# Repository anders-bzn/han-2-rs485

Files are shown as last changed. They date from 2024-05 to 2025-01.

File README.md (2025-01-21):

# han-2-rs485
A small board that converts signal level from the HAN-port on swedish electricity power meter to RS-485. There is no connection for ground so a galvanically separated receiver is recommended. The board fits into a small ELKO standard connection box.

Created with KiCad 7.0 and [kicad-jlcpcb-tools](https://github.com/Bouni/kicad-jlcpcb-tools) plugin for creating fabrication files.

This is used together with a Raspberry Pi with a RS-485 HAT

## Software
Small python program for publishing MQTT data is located in the sw folder. It has one script that sets up the RPi and installs a service. The p1_sensors.yaml is a template for mapping sensors into Home Assistant. The content should be pasted into configuration.yaml in Home Assistant.

Change the han-mqtt-config.yaml with mqtt settings and report interval. Then install configuration and service by running:

    sudo ./han-mqtt.sh

## Acknowledgement
Acknowledgement to this github project: https://github.com/UdoK/esp8266_p1meter_sv from which I copied the mqtt topics.

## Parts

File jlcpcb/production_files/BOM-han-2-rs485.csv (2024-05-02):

Comment | Designator | Footprint | LCSC
USBLC6-2P6 | U2 | SOT-666
4k7 | R4 | R_0805_2012Metric
4k7 | R3 | R_0805_2012Metric
RJ12 | J1 | RJ12_Amphenol_54601
RJ45 | J2 | RJ45_Amphenol_54602-x08_Horizontal
MAX485E | U1 | SOIC-8_3.9x4.9mm_P1.27mm
10k | R2 | R_0805_2012Metric
100n | C1 | C_0805_2012Metric_Pad1.18x1.45mm_HandSolder
120R | R1 | R_0805_2012Metric

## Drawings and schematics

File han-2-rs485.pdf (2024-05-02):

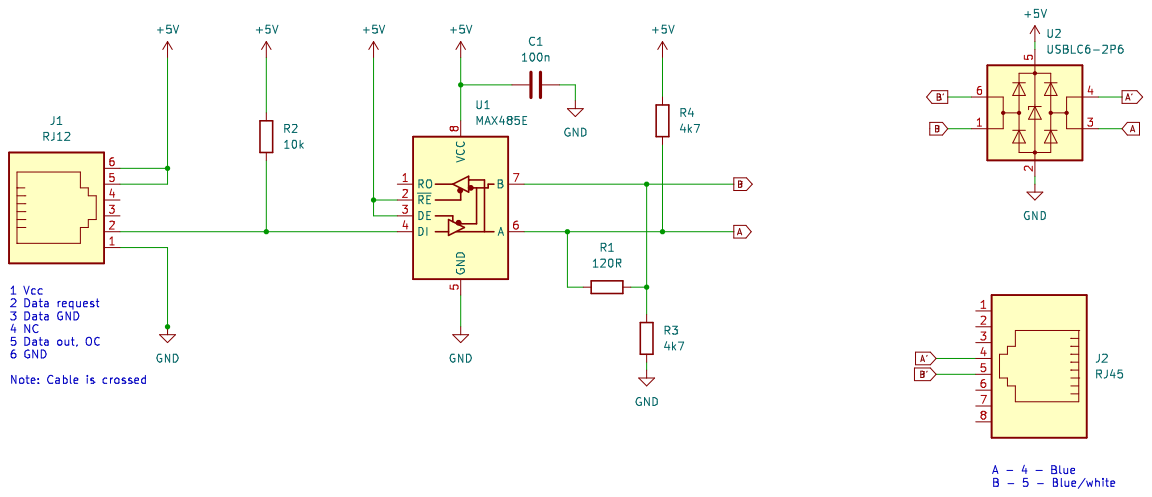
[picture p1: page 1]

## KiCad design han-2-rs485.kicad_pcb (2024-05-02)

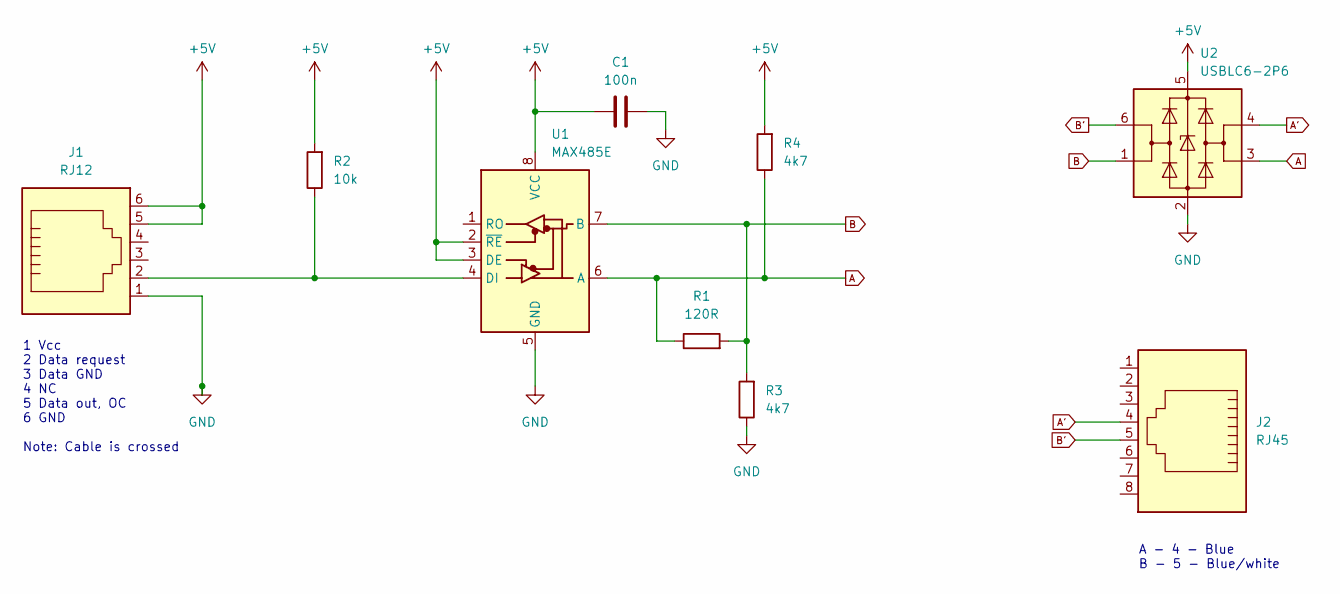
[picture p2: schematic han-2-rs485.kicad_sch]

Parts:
C1: 100n; C_0805_2012Metric_Pad1.18x1.45mm_HandSolder
J1: RJ12; RJ12_Amphenol_54601
J2: RJ45; RJ45_Amphenol_54602-x08_Horizontal
R1: 120R; R_0805_2012Metric
R2: 10k; R_0805_2012Metric
R3, R4: 4k7; R_0805_2012Metric
U1: MAX485E; SOIC-8_3.9x4.9mm_P1.27mm
U2: USBLC6-2P6; SOT-666

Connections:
+5V: C1.1, J1.5, J1.6, R2.2, R4.2, U1.2 (~RE), U1.3 (DE), U1.8 (VCC), U2.5 (VBUS)
A: R1.1, R4.1, U1.6 (A), U2.3 (I/O2)
A': J2.4, U2.4 (I/O2)
B: R1.2, R3.2, U1.7 (B), U2.1 (I/O1)
B': J2.5, U2.6 (I/O1)
GND: C1.2, J1.1, R3.1, U1.5 (GND), U2.2 (GND)
unnamed: J1.2, R2.1, U1.4 (DI)

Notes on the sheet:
1 Vcc 2 Data request 3 Data GND 4 NC 5 Data out, OC 6 GND Note: Cable is crossed
A - 4 - Blue B - 5 - Blue/white

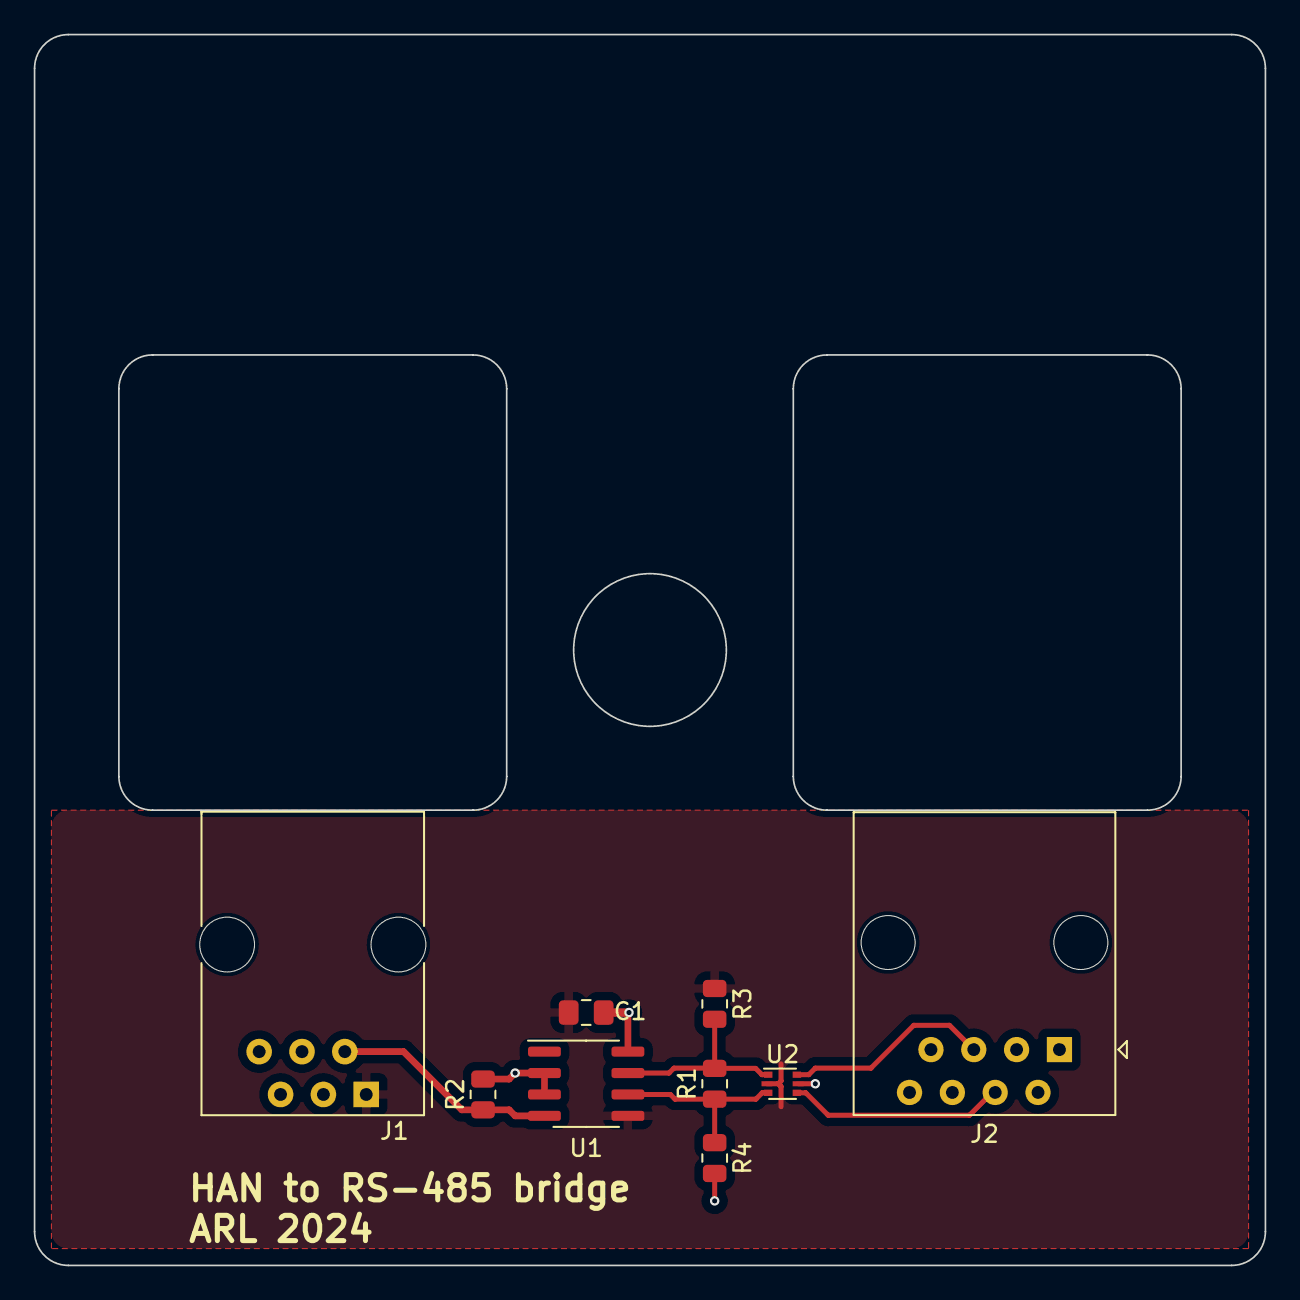
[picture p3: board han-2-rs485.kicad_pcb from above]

Board: 2 copper layers, 73.0 x 73.0 mm, 9 parts (0 on the bottom side), 7 nets.

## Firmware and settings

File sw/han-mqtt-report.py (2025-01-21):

#!/bin/python3

import os
import paho.mqtt.client as mqtt
import paho.mqtt.publish as publish
import re
import serial
import yaml

# Map telegram to mqtt topic
topics = {
    "0-0:1.0.0": "timestamp",
    "1-0:1.8.0": "consumption",
    "1-0:2.8.0": "return_delivery",
    "1-0:3.8.0": "consumption_reactive",
    "1-0:4.8.0": "return_delivery_reactive",
    "1-0:1.7.0": "actual_consumption",
    "1-0:2.7.0": "actual_return_delivery",
    "1-0:3.7.0": "actual_consumption_reactive",
    "1-0:4.7.0": "actual_return_delivery_reactive",
    "1-0:21.7.0": "l1_instant_power_usage",
    "1-0:22.7.0": "l1_instant_power_delivery",
    "1-0:23.7.0": "l1_reactive_power_usage",
    "1-0:24.7.0": "l1_reactive_power_delivery",
    "1-0:41.7.0": "l2_instant_power_usage",
    "1-0:42.7.0": "l2_instant_power_delivery",
    "1-0:43.7.0": "l2_reactive_power_usage",
    "1-0:44.7.0": "l2_reactive_power_delivery",
    "1-0:61.7.0": "l3_instant_power_usage",
    "1-0:62.7.0": "l3_instant_power_delivery",
    "1-0:63.7.0": "l3_reactive_power_usage",
    "1-0:64.7.0": "l3_reactive_power_delivery",
    "1-0:32.7.0": "l1_voltage",
    "1-0:52.7.0": "l2_voltage",
    "1-0:72.7.0": "l3_voltage",
    "1-0:31.7.0": "l1_current",
    "1-0:51.7.0": "l2_current",
    "1-0:71.7.0": "l3_current",
}

root_topic = "sensors/power/p1meter"

def loadConfig(config_file):
    with open(config_file, 'r') as ymlfile:
        try:
            config = yaml.safe_load(ymlfile)
        except yaml.YAMLError as exc:
            print(exc)
    return config

def main(config):
    config_yaml = loadConfig(config)

    # Initialize serial port
    try:
        ser = serial.Serial('/dev/ttyAMA0', 115200, timeout=12)
    except:
        print('FAIL: Could not open serial port')
        exit(1)

    # Initialize the mqtt connection
    client = mqtt.Client()

    if config_yaml['mqtt']['username'] != None and config_yaml['mqtt']['password'] != None:
        client.username_pw_set(config_yaml['mqtt']['username'], config_yaml['mqtt']['password'])

    client.connect(config_yaml['mqtt']['broker'])
    client.loop_start()

    interval = int(config_yaml['mqtt']['report_interval'])

    while True:
        # Just use one telegram of out ten
        for i in range(interval):
            mvpos=0
            line = ser.readline()
            while line[0] != ord('/'):
                line = ser.readline()

        while line[0] != ord('!'):
            line = ser.readline()
            data = (re.split('\*|W|\(', str(line)[2:]))

            if len(data) > 1 and data[0] != "0-0:1.0.0":
                topic = ("{0}/{1}".format(root_topic, topics[data[0]]))
                client.publish(topic, data[1])

    ser.close()

main("/etc/han-mqtt-config.yaml")

""" This is a telegram example
'0-0:1.0.0(250107213151W)\r\n'
'1-0:1.8.0(00006156.203*kWh)\r\n'
'1-0:2.8.0(00009012.076*kWh)\r\n'
'1-0:3.8.0(00000003.237*kvarh)\r\n'
'1-0:4.8.0(00003778.093*kvarh)\r\n'
'1-0:1.7.0(0001.999*kW)\r\n'
'1-0:2.7.0(0000.000*kW)\r\n'
'1-0:3.7.0(0000.000*kvar)\r\n'
'1-0:4.7.0(0000.623*kvar)\r\n'
'1-0:21.7.0(0000.279*kW)\r\n'
'1-0:41.7.0(0000.807*kW)\r\n'
'1-0:61.7.0(0000.912*kW)\r\n'
'1-0:22.7.0(0000.000*kW)\r\n'
'1-0:42.7.0(0000.000*kW)\r\n'
'1-0:62.7.0(0000.000*kW)\r\n'
'1-0:23.7.0(0000.000*kvar)\r\n'
'1-0:43.7.0(0000.000*kvar)\r\n'
'1-0:63.7.0(0000.000*kvar)\r\n'
'1-0:24.7.0(0000.357*kvar)\r\n'
'1-0:44.7.0(0000.165*kvar)\r\n'
'1-0:64.7.0(0000.100*kvar)\r\n'
'1-0:32.7.0(235.2*V)\r\n'
'1-0:52.7.0(235.9*V)\r\n'
'1-0:72.7.0(237.0*V)\r\n'
'1-0:31.7.0(002.0*A)\r\n'
'1-0:51.7.0(003.6*A)\r\n'
'1-0:71.7.0(003.9*A)\r\n'
"""

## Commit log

2024-05-02 Generated schematic pdf
2025-01-18 sw: Renamed instant_power_current to current
2025-01-21 Use correct topic mapping
    [han-mqtt-report.py]
